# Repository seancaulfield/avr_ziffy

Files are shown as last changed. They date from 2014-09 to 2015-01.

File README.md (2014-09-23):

avr_ziffy
=========

Arduino shield with a plethora of ZIF sockets to allow programming of all the
various Atmel AVR chips.

The hardware directory should contain the Eagle CAD project files needed to
build the board. Since they're Not Exactly Code but still open hardware, I'm
licensing them under Creative Commons Attribution Share Alike license.

I've modified the sample code provided with the Arduino distribution for the
firmware files, both because I needed to ensure all the pins would line up and
also do fix a few problems/lack of clarity in the source code Sicne this was
originally under a 2-clause BSD license, I will stick to that for my fork of
the code.

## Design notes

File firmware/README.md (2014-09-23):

avr_ziffy - Firmware
=========

I've modified the sample code provided with the Arduino distribution for the
firmware files, both because I needed to ensure all the pins would line up and
also do fix a few problems/lack of clarity in the source code Sicne this was
originally under a 2-clause BSD license, I will stick to that for my fork of
the code.

I've been using the Python CLI tool ino to handle building w/o using the
Arduino GUI, which is why the directory layout and wierdo ino.ini file.
However, it should be backwards compatible with the Arduino GUI.

No libraries outside of the basic Arduino ones should be required.

The bulk of credit of course goes to those developers who have gone before me:
* Randall Bohn
* David A. Mellis

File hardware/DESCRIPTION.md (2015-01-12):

"ZIFfy" AVR ISP Shield
======================

Summary
-------

Riff on the version(s) from SparkFun, EvilMadScientist, and my own insane ideas while trying to learn to use EAGLE.

Licensed under the Creative Commons, version 4.0 ported, attribution & share-alike (CC-4.0-BY-SA).

Revision History
----------------

*Revison 1.0* - TODO

*Revison 2.0* - TODO

*Revison 3.0* - TODO

*Revison 4.0* - Relayout, including punting the DIP20 socket that I've yet to use as well as shortening the whole shield for cost reasons. Clock and voltage select support removed since they didn't seem to be necessary, either.

*Revison 5.0* - Instead of using separate ZIF sockets, use a ridiculous 6P4T mechanical switch to select which lines go to which pins. Supports programming any AVR via the ISP connector, and the following via the onboard ZIF socket:

* ATTiny 25/45/85
* ATTiny 24/44/84
* ATTiny 2313/4313
* ATMega 328P

*Revison 6.0* - Instead of using separate ZIF sockets or a ridiculous 6P4T mechanical switch, use 6 74'125 buffer chips to drive the various lines to the correct pins. Mostly pin compatibile with existing firmware, but to properly use the buffers requires 4 more GPIO lines to select the chip type. Supports programming any AVR via the ISP connector, and the following via the onboard ZIF socket:
* ATTiny 25/45/85
* ATTiny 24/44/84
* ATTiny 2313/4313
* ATMega 328P

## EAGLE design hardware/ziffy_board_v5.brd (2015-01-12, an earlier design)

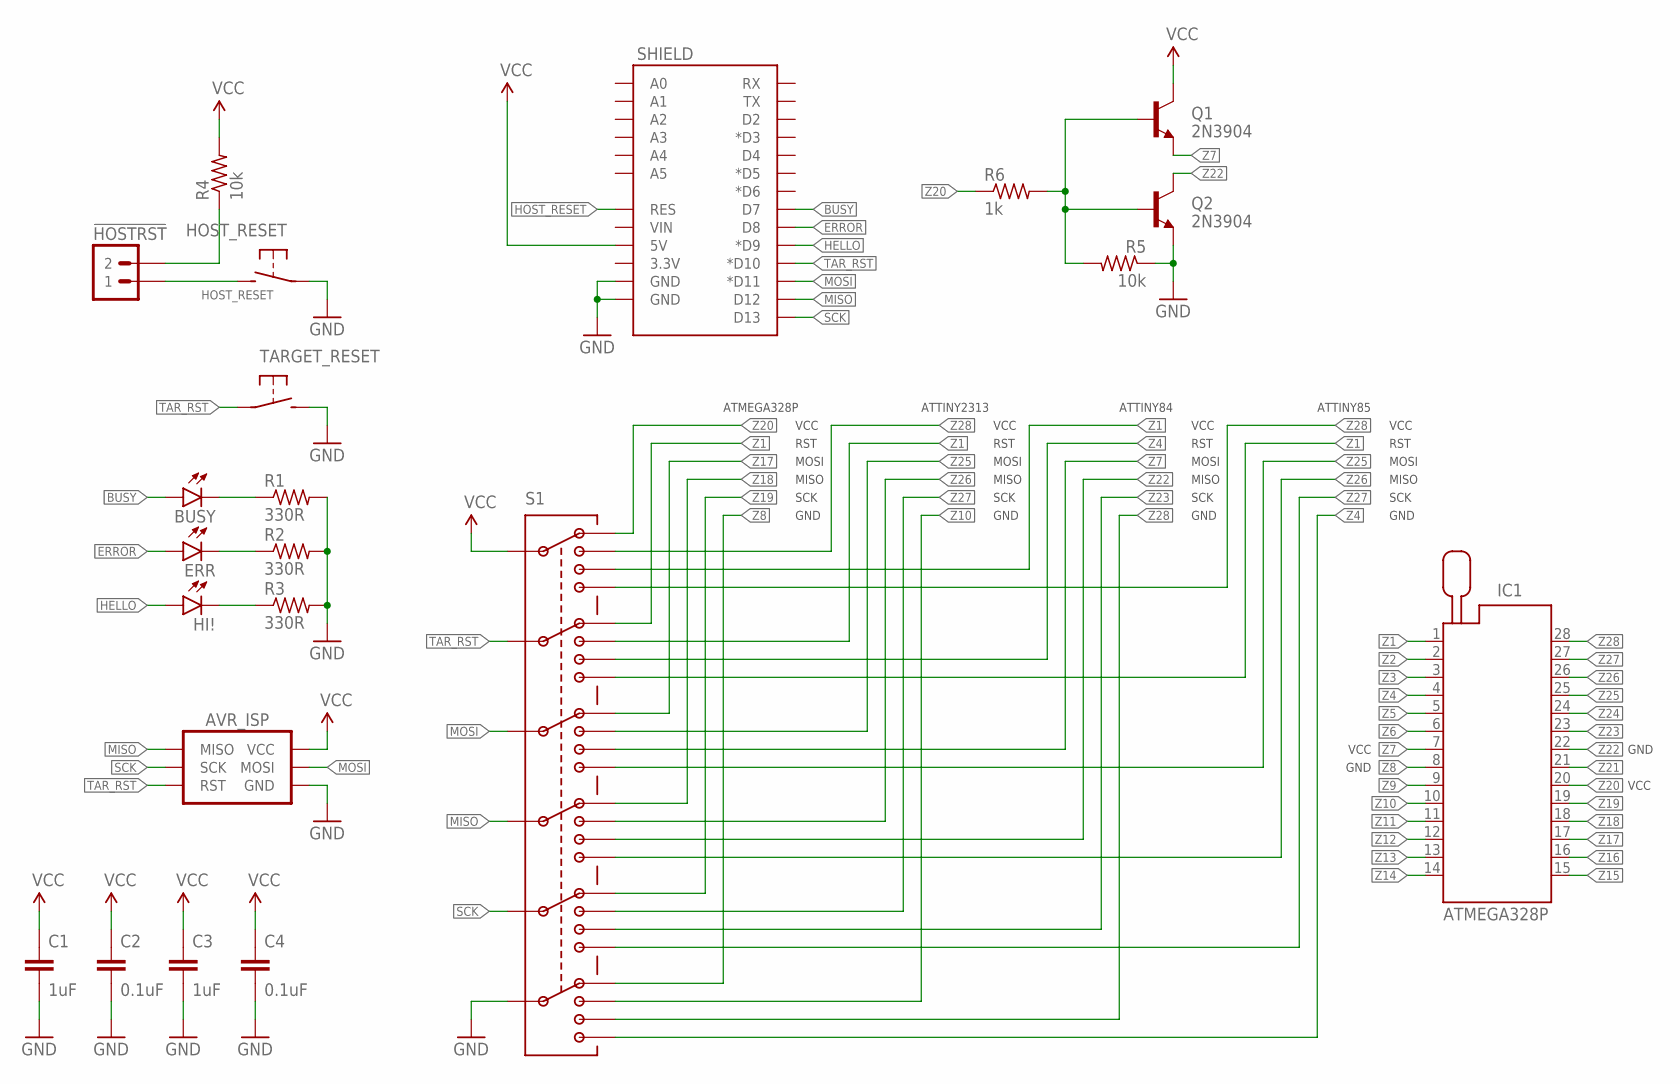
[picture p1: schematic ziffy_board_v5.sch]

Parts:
!HOSTRST: M02PTH; 1X02
AVR_ISP: AVR_SPI_PRG_6PTH-SHROUD; 2X3-SHROUDED
BUSY: YELLOW; LED3MM
C1, C3: 1uF; C025-024X044
C2, C4: 0.1uF; C025-024X044
ERR: RED; LED3MM
HI!: GREEN; LED3MM
HOST_RESET: SPST-NO-TACT6MM-PTH-SMALL-PADS; DTS-6-SMALL-PADS
IC1: ATMEGA328P; ZIF28
Q1, Q2: 2N3904; TO-92-AMMO
R1, R2, R3: 330R; RESISTOR-AXIAL-PTH-6.35MM
R4, R5: 10k; RESISTOR-AXIAL-PTH-6.35MM
R6: 1k; RESISTOR-AXIAL-PTH-6.35MM
S1: SWITCH-6P4TASDFADSFSD; SWITCH-6P4T-2MMPTH
SHIELD: ARDUINO_SHIELD_SMALLER; ARDUINO_SHIELD_NOOUTLINE_INSIDE_SMALLER
TARGET_RESET: SPST-NO-TACT6MM-PTH-SMALL-PADS; DTS-6-SMALL-PADS

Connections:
BUSY: BUSY.A, SHIELD.D7
ERROR: ERR.A, SHIELD.D8
GND: AVR_ISP.6 (GND), C1.2, C2.2, C3.2, C4.2, HOST_RESET.1, HOST_RESET.2 (1), Q2.1 (E), R1.P$2 (2), R2.P$2 (2), R3.P$2 (2), R5.P$1 (1), S1.P28 (28), SHIELD.GND@0 (GND), SHIELD.GND@1 (GND), TARGET_RESET.3 (2), TARGET_RESET.4 (2)
HELLO: HI!.A, SHIELD.D9 (*D9)
HOST_RESET: !HOSTRST.1, HOST_RESET.3 (2), HOST_RESET.4 (2), SHIELD.RES
MISO: AVR_ISP.1 (MISO), S1.P18 (18), SHIELD.D12
MOSI: AVR_ISP.4 (MOSI), S1.P13 (13), SHIELD.D11 (*D11)
unnamed: BUSY.K (C), R1.P$1 (1)
unnamed: ERR.K (C), R2.P$1 (1)
unnamed: HI!.K (C), R3.P$1 (1)
unnamed: !HOSTRST.2, R4.P$1 (1)
unnamed: Q1.2 (B), Q2.2 (B), R5.P$2 (2), R6.P$2 (2)
SCK: AVR_ISP.3 (SCK), S1.P23 (23), SHIELD.D13
TAR_RST: AVR_ISP.5 (RST), S1.P8 (8), SHIELD.D10 (*D10), TARGET_RESET.1, TARGET_RESET.2 (1)
VCC: AVR_ISP.2 (VCC), C1.1, C2.1, C3.1, C4.1, Q1.3 (C), R4.P$2 (2), S1.P3 (3), SHIELD.5V
Z1: IC1.1, S1.P4 (4), S1.P6 (6), S1.P7 (7), S1.P10 (10)
Z2: IC1.2
Z3: IC1.3
Z4: IC1.4, S1.P9 (9), S1.P30 (30)
Z5: IC1.5
Z6: IC1.6
Z7: IC1.7, Q1.1 (E), S1.P14 (14)
Z8: IC1.8, S1.P26 (26)
Z9: IC1.9
Z10: IC1.10, S1.P27 (27)
Z11: IC1.11
Z12: IC1.12
Z13: IC1.13
Z14: IC1.14
Z15: IC1.15
Z16: IC1.16
Z17: IC1.17, S1.P11 (11)
Z18: IC1.18, S1.P16 (16)
Z19: IC1.19, S1.P21 (21)
Z20: IC1.20, R6.P$1 (1), S1.P1 (1)
Z21: IC1.21
Z22: IC1.22, Q2.3 (C), S1.P19 (19)
Z23: IC1.23, S1.P24 (24)
Z24: IC1.24
Z25: IC1.25, S1.P12 (12), S1.P15 (15)
Z26: IC1.26, S1.P17 (17), S1.P20 (20)
Z27: IC1.27, S1.P22 (22), S1.P25 (25)
Z28: IC1.28, S1.P2 (2), S1.P5 (5), S1.P29 (29)

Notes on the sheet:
ATMEGA328P
ATTINY2313
ATTINY84
ATTINY85
VCC
RST
MOSI
MISO
SCK
GND

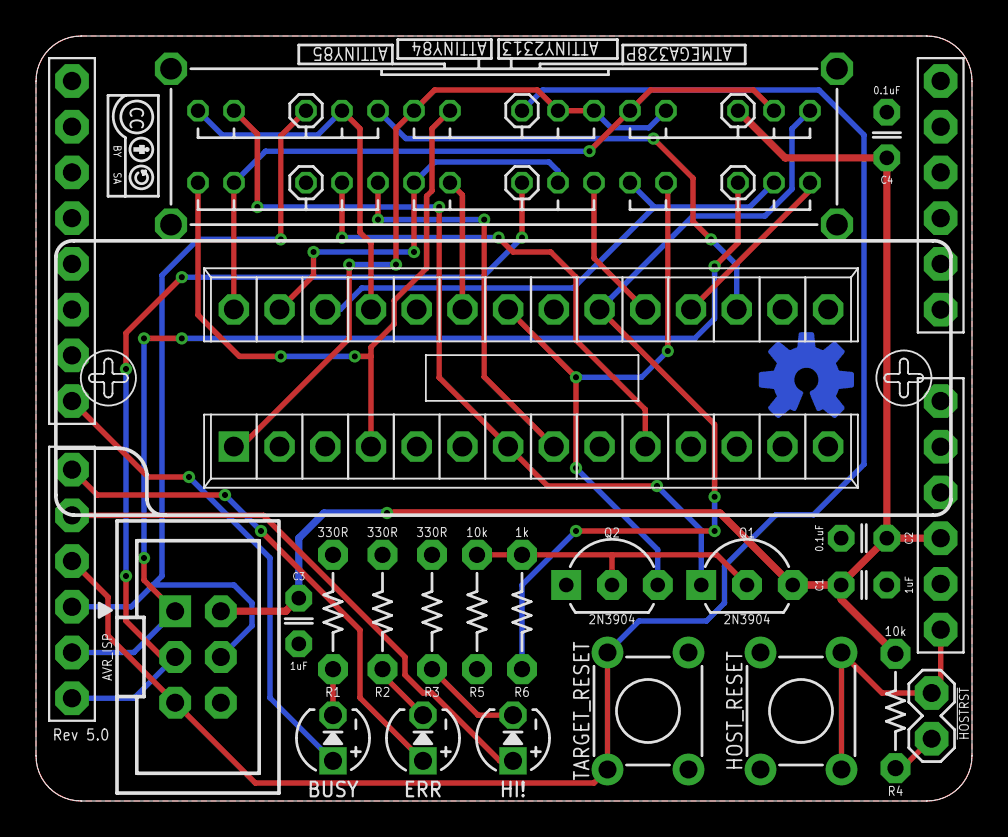
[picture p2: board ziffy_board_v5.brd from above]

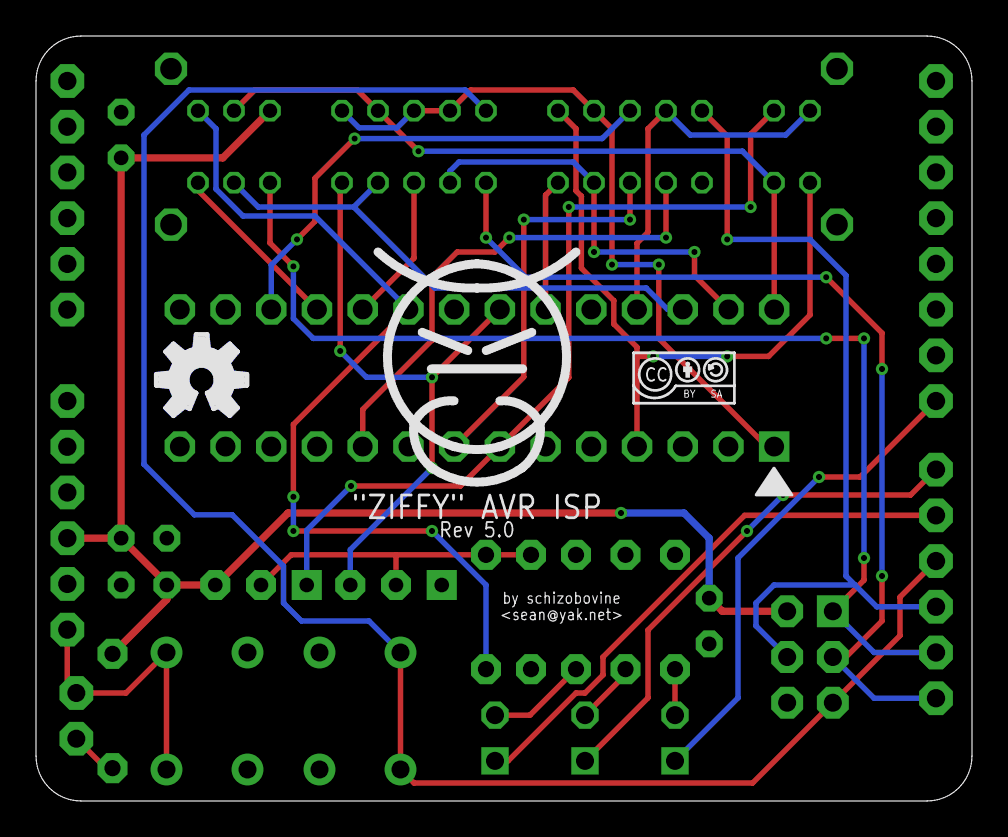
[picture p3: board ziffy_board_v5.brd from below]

Board: 2 copper layers, 52.0 x 42.5 mm, 26 parts (2 on the bottom side), 30 nets.

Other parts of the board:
U$1, U$5: CC-BY-SA-4.0-NO-URL
U$2: COW
U$3: OSHWLOGO_BOT_0.2

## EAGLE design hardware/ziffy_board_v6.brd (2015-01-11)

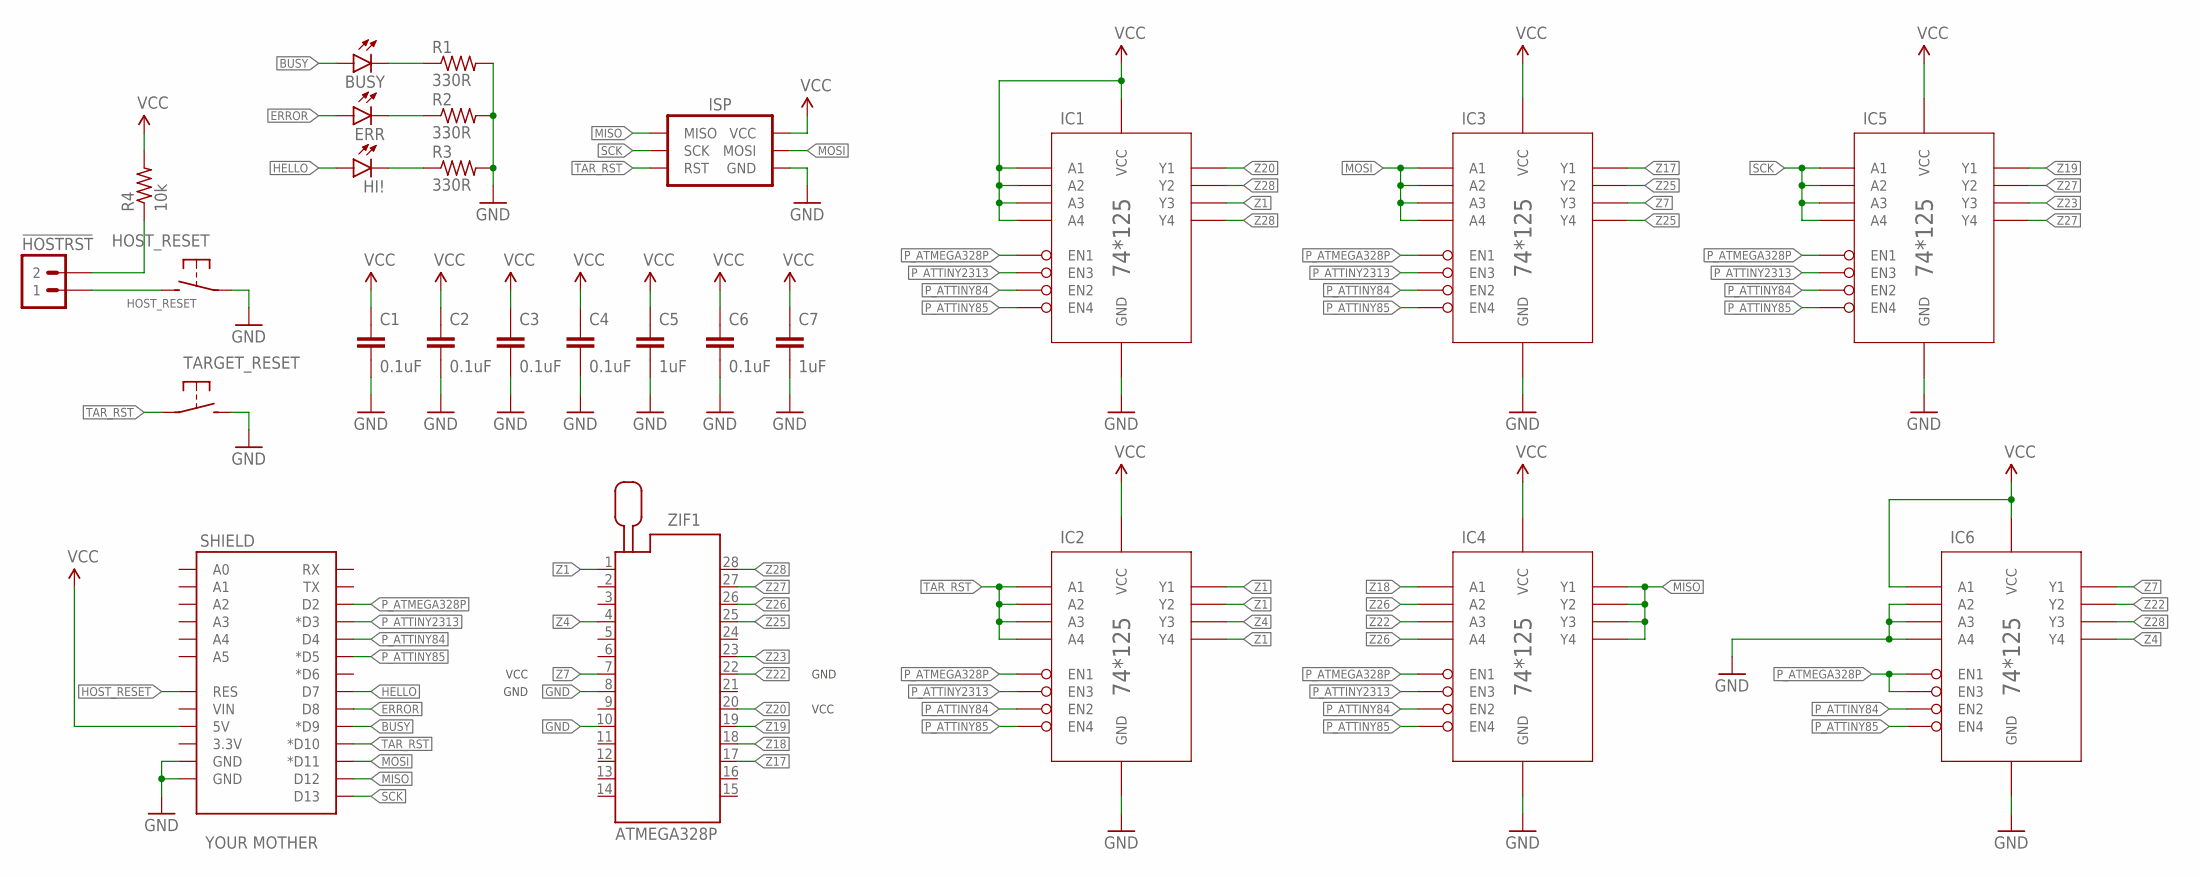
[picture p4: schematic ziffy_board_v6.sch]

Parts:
!HOSTRST: M02PTH; 1X02
BUSY: YELLOW; LED3MM
C1, C2, C3, C4, C6: 0.1uF; C025-024X044
C5, C7: 1uF; C025-024X044
ERR: RED; LED3MM
HI!: GREEN; LED3MM
HOST_RESET: SPST-NO-TACT6MM-PTH-SMALL-PADS; DTS-6-SMALL-PADS
IC1, IC2, IC3, IC4, IC5, IC6: 74HC125; SO14
ISP: AVR_SPI_PRG_6PTH-SHROUD; 2X3-SHROUDED
R1, R2, R3: 330R; RESISTOR-AXIAL-PTH-5.08MM
R4: 10k; RESISTOR-AXIAL-PTH-5.08MM
SHIELD: YOUR MOTHER; ARDUINO_SHIELD_NOOUTLINE_INSIDE_SMALLER
TARGET_RESET: SPST-NO-TACT6MM-PTH-SMALL-PADS; DTS-6-SMALL-PADS
ZIF1: ATMEGA328P; ZIF28

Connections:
BUSY: BUSY.A, SHIELD.D9 (*D9)
ERROR: ERR.A, SHIELD.D8
GND: C1.2, C2.2, C3.2, C4.2, C5.2, C6.2, C7.2, HOST_RESET.1, HOST_RESET.2 (1), IC1.7 (GND), IC2.7 (GND), IC3.7 (GND), IC4.7 (GND), IC5.7 (GND), IC6.5 (A2), IC6.7 (GND), IC6.9 (A3), IC6.12 (A4), ISP.6 (GND), R1.P$2 (2), R2.P$2 (2), R3.P$2 (2), SHIELD.GND@0 (GND), SHIELD.GND@1 (GND), TARGET_RESET.3 (2), TARGET_RESET.4 (2), ZIF1.8, ZIF1.10
HELLO: HI!.A, SHIELD.D7
HOST_RESET: !HOSTRST.1, HOST_RESET.3 (2), HOST_RESET.4 (2), SHIELD.RES
MISO: IC4.3 (Y1), IC4.6 (Y2), IC4.8 (Y3), IC4.11 (Y4), ISP.1 (MISO), SHIELD.D12
MOSI: IC3.2 (A1), IC3.5 (A2), IC3.9 (A3), IC3.12 (A4), ISP.4 (MOSI), SHIELD.D11 (*D11)
unnamed: BUSY.K (C), R1.P$1 (1)
unnamed: ERR.K (C), R2.P$1 (1)
unnamed: HI!.K (C), R3.P$1 (1)
unnamed: !HOSTRST.2, R4.P$1 (1)
P_ATMEGA328P: IC1.1 (EN1), IC2.1 (EN1), IC3.1 (EN1), IC4.1 (EN1), IC5.1 (EN1), IC6.1 (EN1), IC6.10 (EN3), SHIELD.D2
P_ATTINY84: IC1.4 (EN2), IC2.4 (EN2), IC3.4 (EN2), IC4.4 (EN2), IC5.4 (EN2), IC6.4 (EN2), SHIELD.D4
P_ATTINY85: IC1.13 (EN4), IC2.13 (EN4), IC3.13 (EN4), IC4.13 (EN4), IC5.13 (EN4), IC6.13 (EN4), SHIELD.D5 (*D5)
P_ATTINY2313: IC1.10 (EN3), IC2.10 (EN3), IC3.10 (EN3), IC4.10 (EN3), IC5.10 (EN3), SHIELD.D3 (*D3)
SCK: IC5.2 (A1), IC5.5 (A2), IC5.9 (A3), IC5.12 (A4), ISP.3 (SCK), SHIELD.D13
TAR_RST: IC2.2 (A1), IC2.5 (A2), IC2.9 (A3), IC2.12 (A4), ISP.5 (RST), SHIELD.D10 (*D10), TARGET_RESET.1, TARGET_RESET.2 (1)
VCC: C1.1, C2.1, C3.1, C4.1, C5.1, C6.1, C7.1, IC1.2 (A1), IC1.5 (A2), IC1.9 (A3), IC1.12 (A4), IC1.14 (VCC), IC2.14 (VCC), IC3.14 (VCC), IC4.14 (VCC), IC5.14 (VCC), IC6.2 (A1), IC6.14 (VCC), ISP.2 (VCC), R4.P$2 (2), SHIELD.5V
Z1: IC1.8 (Y3), IC2.3 (Y1), IC2.6 (Y2), IC2.11 (Y4), ZIF1.1
Z4: IC2.8 (Y3), IC6.11 (Y4), ZIF1.4
Z7: IC3.8 (Y3), IC6.3 (Y1), ZIF1.7
Z17: IC3.3 (Y1), ZIF1.17
Z18: IC4.2 (A1), ZIF1.18
Z19: IC5.3 (Y1), ZIF1.19
Z20: IC1.3 (Y1), ZIF1.20
Z22: IC4.9 (A3), IC6.6 (Y2), ZIF1.22
Z23: IC5.8 (Y3), ZIF1.23
Z25: IC3.6 (Y2), IC3.11 (Y4), ZIF1.25
Z26: IC4.5 (A2), IC4.12 (A4), ZIF1.26
Z27: IC5.6 (Y2), IC5.11 (Y4), ZIF1.27
Z28: IC1.6 (Y2), IC1.11 (Y4), IC6.8 (Y3), ZIF1.28

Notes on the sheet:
VCC
GND

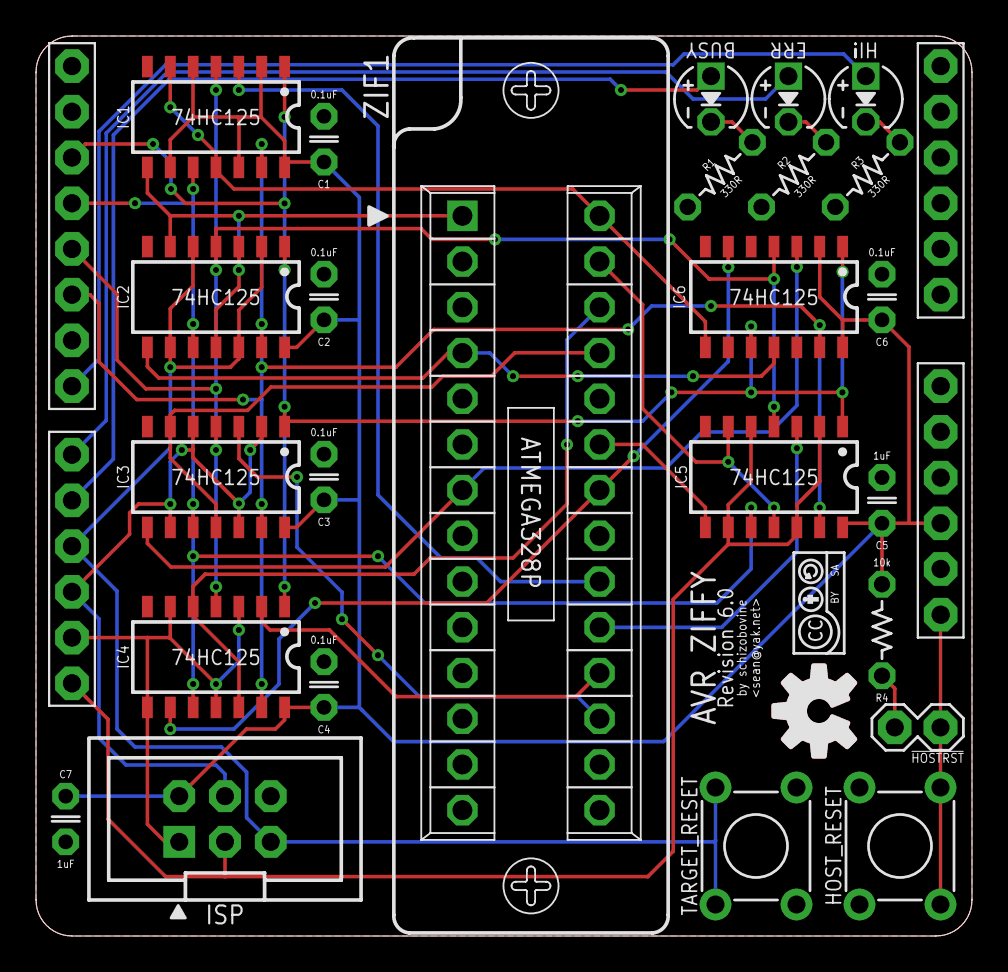
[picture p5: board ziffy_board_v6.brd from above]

Board: 2 copper layers, 52.0 x 50.0 mm, 28 parts (0 on the bottom side), 31 nets.

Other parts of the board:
U$1: CC-BY-SA-4.0-NO-URL
U$2: OSHWLOGO_TOP_0.2_A

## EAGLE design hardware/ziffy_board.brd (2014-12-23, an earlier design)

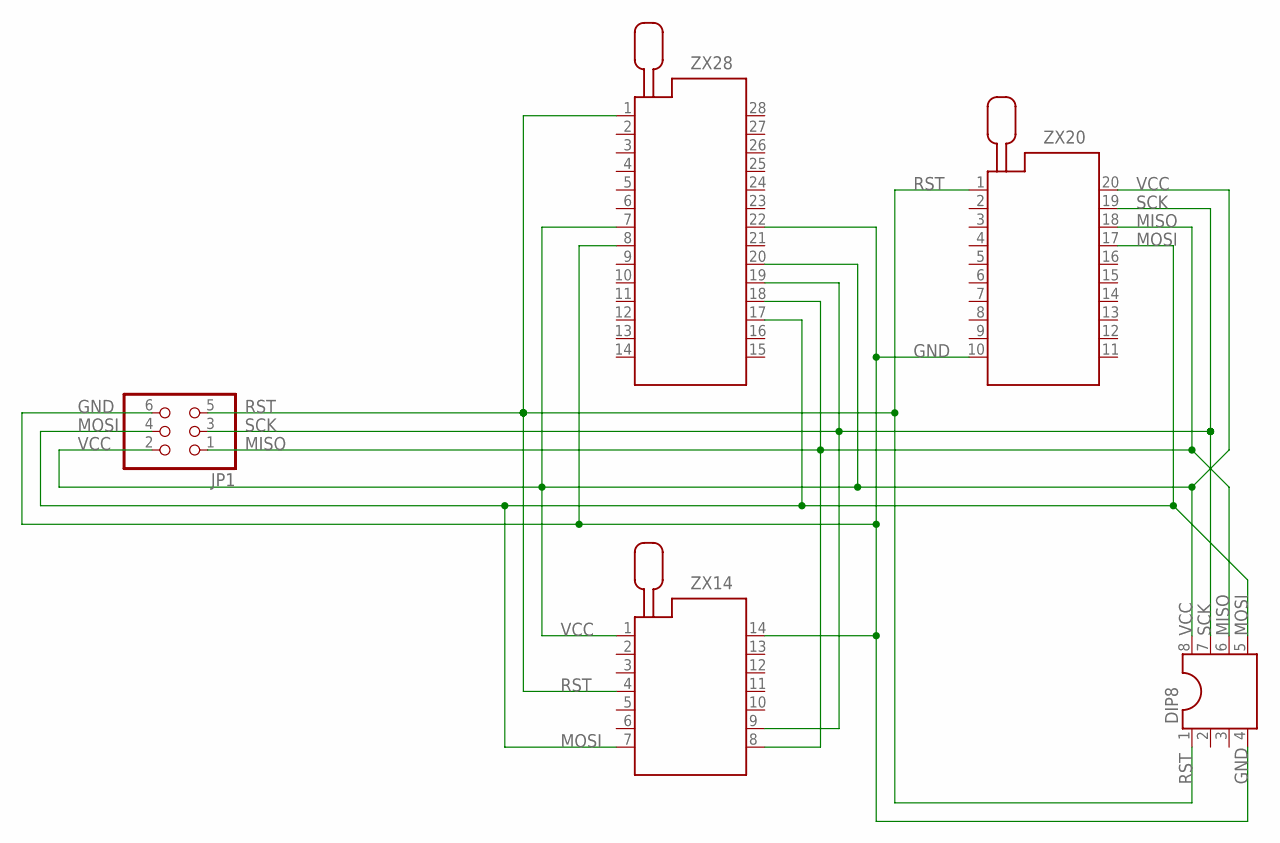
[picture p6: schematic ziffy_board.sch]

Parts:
DIP8: DIL8S; SOCKET-08
JP1: PINHD-2X3; 2X03
ZX14: 214-3339-00-0602J
ZX20: 220-3342-00-0602J
ZX28: 228-4817-00-0602J

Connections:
GND: DIP8.4, JP1.6, ZX14.14, ZX20.10, ZX28.8, ZX28.22
MISO: DIP8.6, JP1.1, ZX14.8, ZX20.18, ZX28.18
MOSI: DIP8.5, JP1.4, ZX14.7, ZX20.17, ZX28.17
RST: DIP8.1, JP1.5, ZX14.4, ZX20.1, ZX28.1
SCK: DIP8.7, JP1.3, ZX14.9, ZX20.19, ZX28.19
VCC: DIP8.8, JP1.2, ZX14.1, ZX20.20, ZX28.7, ZX28.20

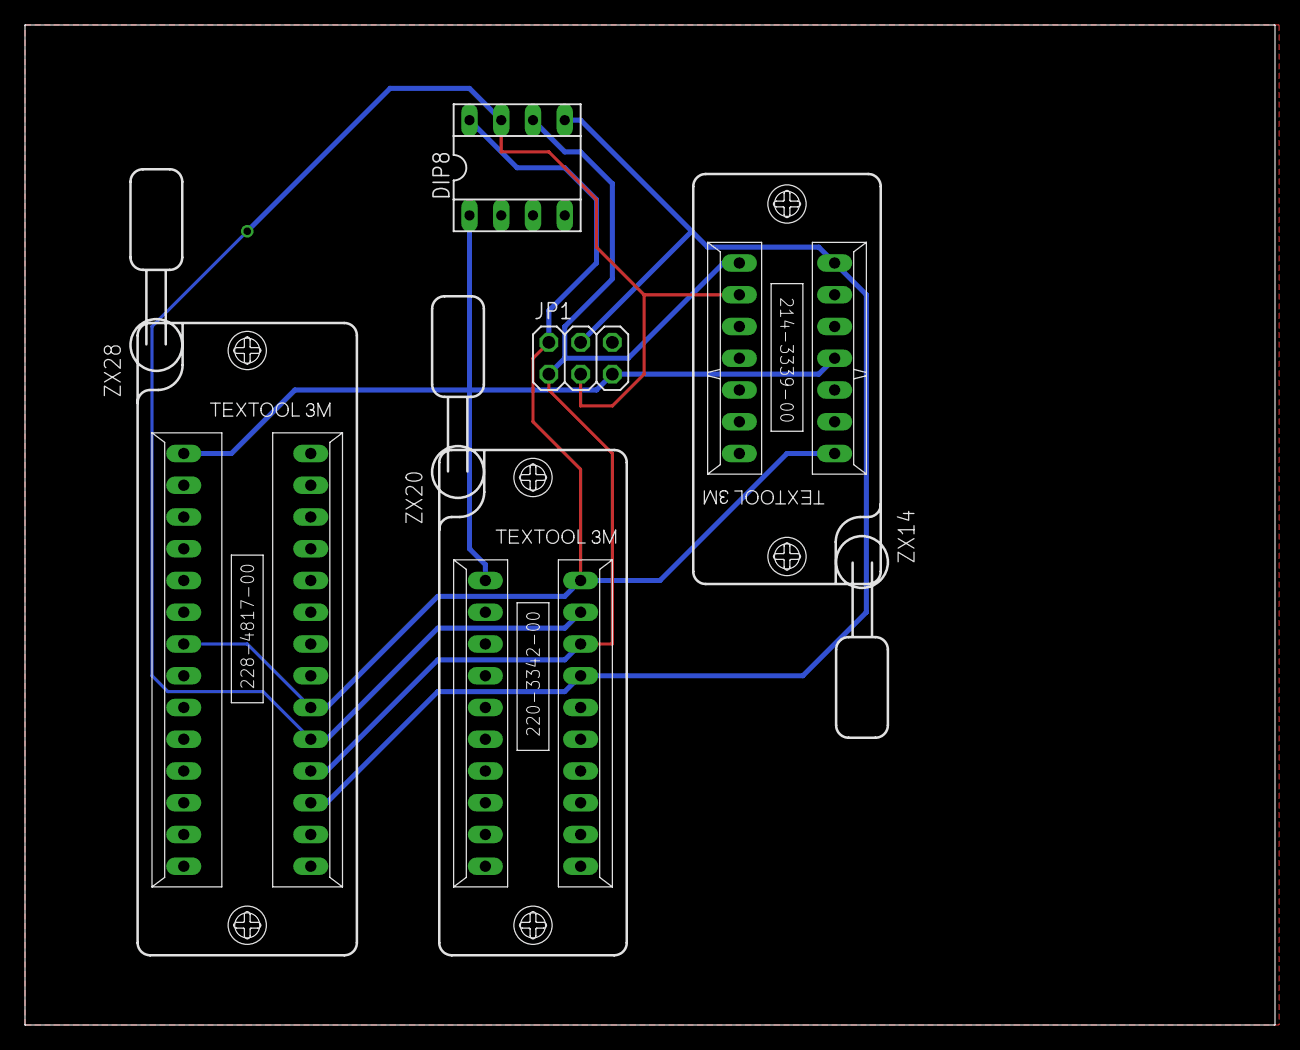
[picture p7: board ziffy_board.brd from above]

Board: 2 copper layers, 100.0 x 80.0 mm, 5 parts (0 on the bottom side), 6 nets.

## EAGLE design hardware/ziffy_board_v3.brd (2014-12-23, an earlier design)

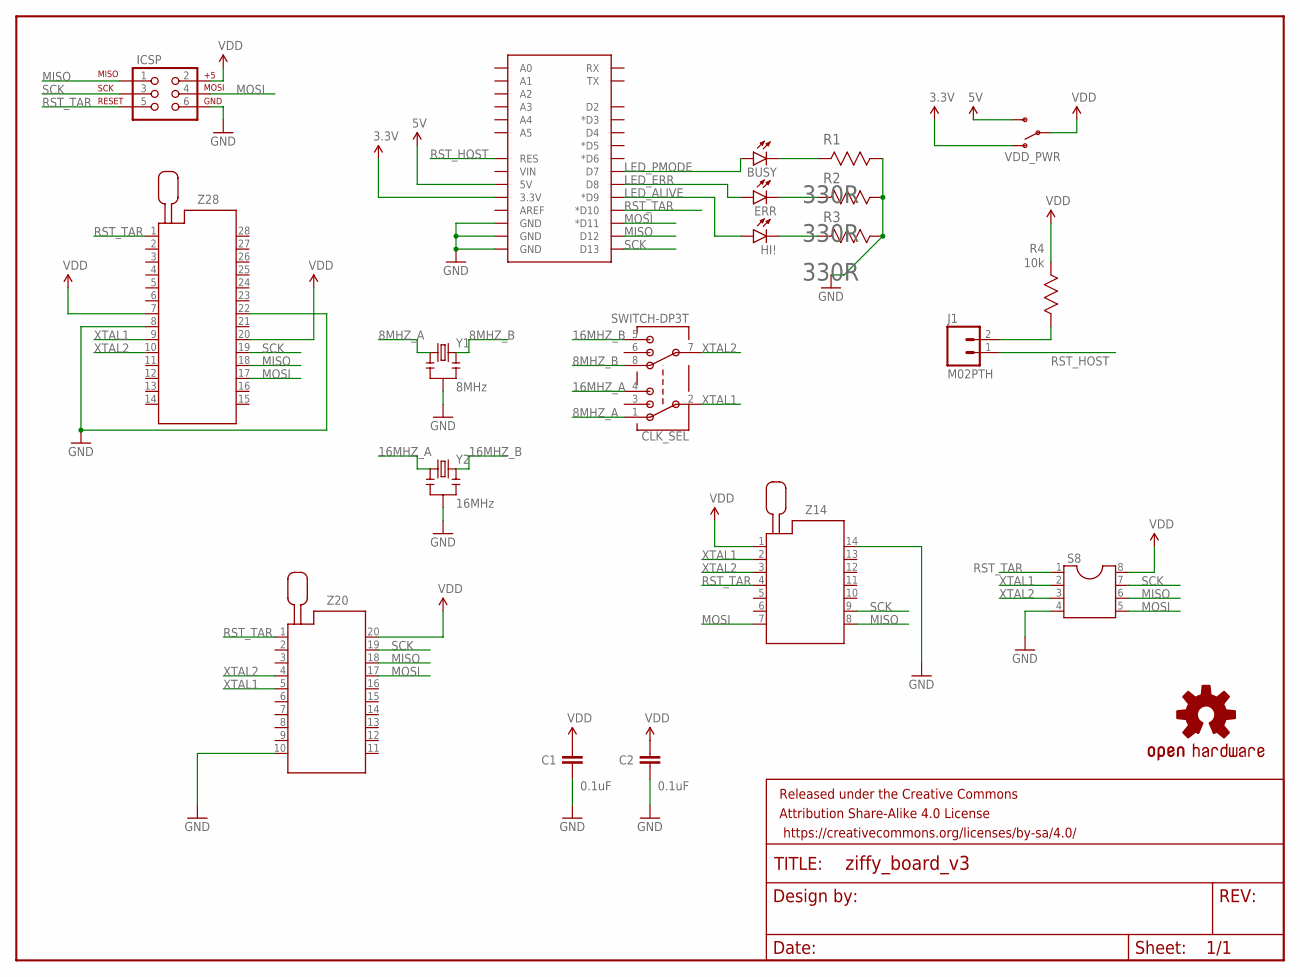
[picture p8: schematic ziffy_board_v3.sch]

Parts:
BUSY: YELLOW; LED3MM
C1, C2: 0.1uF; CAP-PTH-SMALL2
CLK_SEL: SWITCH-DP3T
ERR: RED; LED3MM
FRAME1: FRAME-LETTER; CREATIVE_COMMONS
HI!: GREEN; LED3MM
ICSP: AVR_SPI_PRG_6PTH; 2X3
J1: M02PTH; 1X02
LOGO2: OSHW-LOGOS; OSHW-LOGO-S
R1, R2, R3: 330R; AXIAL-0.2
R4: 10k; AXIAL-0.2
S8: DIPSHIT; DIL08
U$1: ARDUINO_SHIELDOUTLINE_NOHOLES; ARDUINO_SHIELD_OUTLINE_NOHOLES
VDD_PWR: SPDT; SWITCH-SPDT
Y1: 8MHz; RESONATOR-PTH
Y2: 16MHz; RESONATOR-PTH
Z14: ZIF14
Z20: ZIF20
Z28: ZIF28

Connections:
3.3V: U$1.3.3V, VDD_PWR.1 (O)
5V: U$1.5V, VDD_PWR.3 (S)
8MHZ_A: CLK_SEL.1, Y1.1
8MHZ_B: CLK_SEL.8, Y1.3
16MHZ_A: CLK_SEL.4, Y2.1
16MHZ_B: CLK_SEL.5, Y2.3
GND: C1.2, C2.2, ICSP.6, R1.P$1 (2), R2.P$1 (2), R3.P$1 (2), S8.4, U$1.GND@0 (GND), U$1.GND@1 (GND), U$1.GND@2 (GND), Y1.2, Y2.2, Z14.14, Z20.10, Z28.8, Z28.22
LED_ALIVE: HI!.A, U$1.D9 (*D9)
LED_ERR: ERR.A, U$1.D8
LED_PMODE: BUSY.A, U$1.D7
MISO: ICSP.1, S8.6, U$1.D12, Z14.8, Z20.18, Z28.18
MOSI: ICSP.4, S8.5, U$1.D11 (*D11), Z14.7, Z20.17, Z28.17
unnamed: BUSY.K (C), R1.P$2 (1)
unnamed: ERR.K (C), R2.P$2 (1)
unnamed: HI!.K (C), R3.P$2 (1)
unnamed: J1.2, R4.P$1 (2)
RST_HOST: J1.1, U$1.RES
RST_TAR: ICSP.5, S8.1, U$1.D10 (*D10), Z14.4, Z20.1, Z28.1
SCK: ICSP.3, S8.7, U$1.D13, Z14.9, Z20.19, Z28.19
VDD: C1.1, C2.1, ICSP.2, R4.P$2 (1), S8.8, VDD_PWR.2, Z14.1, Z20.20, Z28.7, Z28.20
XTAL1: CLK_SEL.2, S8.2, Z14.2, Z20.5, Z28.9
XTAL2: CLK_SEL.7, S8.3, Z14.3, Z20.4, Z28.10

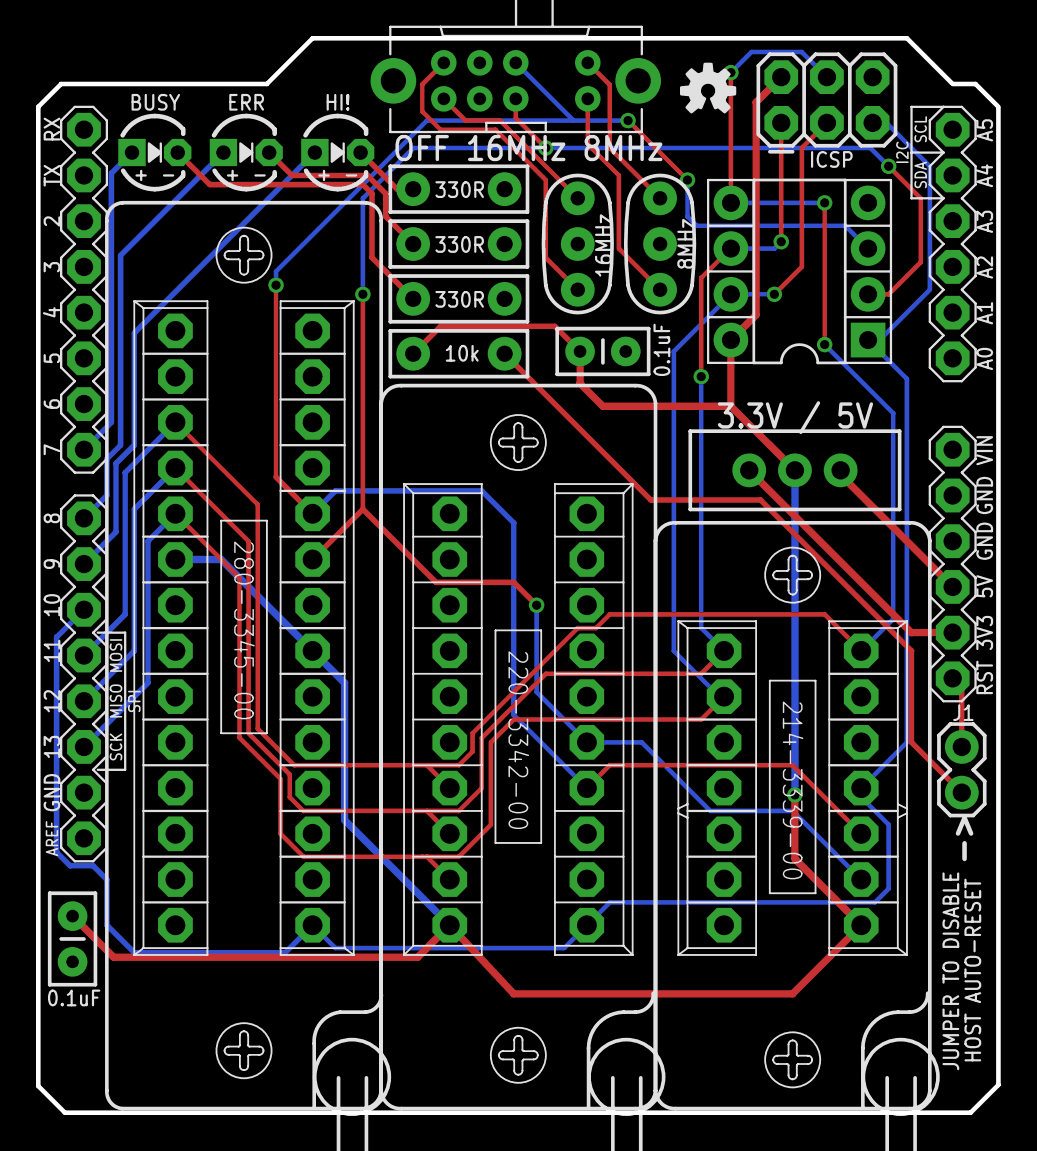
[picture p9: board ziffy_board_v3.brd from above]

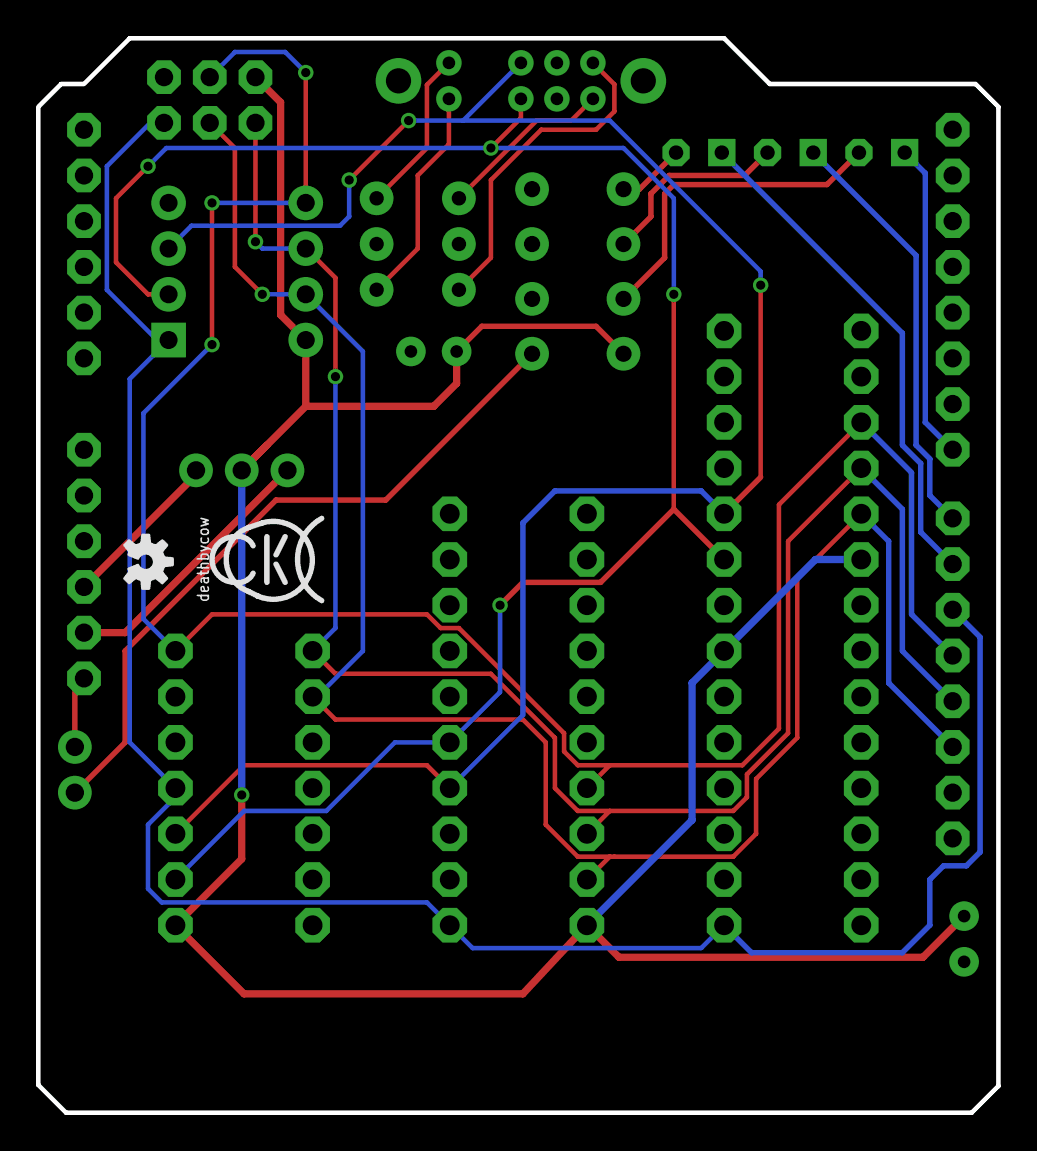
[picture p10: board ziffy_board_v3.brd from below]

Board: 2 copper layers, 53.3 x 59.7 mm, 24 parts (2 on the bottom side), 22 nets.

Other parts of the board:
LOGO1: OSHW-LOGOS; OSHW-LOGO-S
U$3: COW_SMALL

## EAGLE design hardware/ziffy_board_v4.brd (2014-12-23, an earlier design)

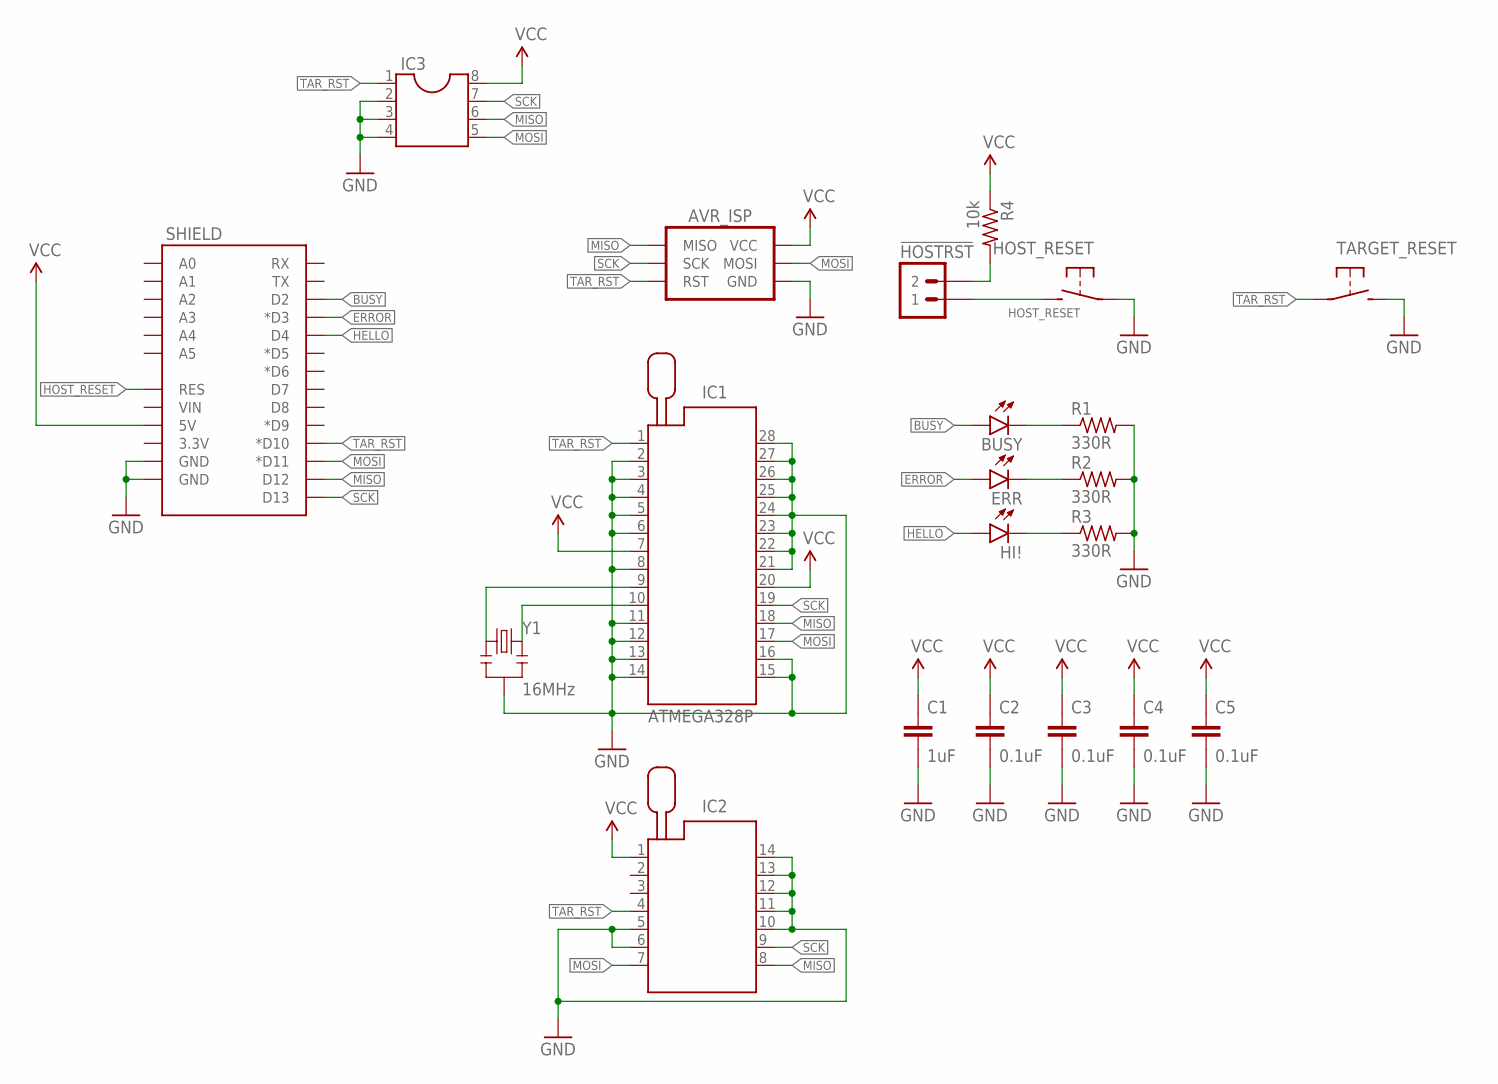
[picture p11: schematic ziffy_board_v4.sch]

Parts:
!HOSTRST: M02PTH; 1X02
AVR_ISP: AVR_SPI_PRG_6PTH-SHROUD; 2X3-SHROUDED
BUSY: YELLOW; LED3MM
C1: 1uF; C025-024X044
C2, C3, C4, C5: 0.1uF; C025-024X044
ERR: RED; LED3MM
HI!: GREEN; LED3MM
HOST_RESET: SPST-NO-TACT3MM-PTH-SMALL-PADS; DTS-3-SMALL-PADS
IC1: ATMEGA328P; ZIF28
IC2: ATTINY84; ZIF14
IC3: DIL8; DIL08
R1, R2, R3: 330R; RESISTOR-AXIAL-PTH-6.35MM
R4: 10k; RESISTOR-AXIAL-PTH-5.08MM
SHIELD: ARDUINO_SHIELD_SMALLER; ARDUINO_SHIELD_NOOUTLINE_INSIDE_SMALLER
TARGET_RESET: SPST-NO-TACT3MM-PTH-SMALL-PADS; DTS-3-SMALL-PADS
Y1: 16MHz; RESONATOR-PTH

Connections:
BUSY: BUSY.A, SHIELD.D2
ERROR: ERR.A, SHIELD.D3 (*D3)
GND: AVR_ISP.6 (GND), C1.2, C2.2, C3.2, C4.2, C5.2, HOST_RESET.1, IC1.2, IC1.3, IC1.4, IC1.5, IC1.6, IC1.8, IC1.11, IC1.12, IC1.13, IC1.14, IC1.15, IC1.16, IC1.21, IC1.22, IC1.23, IC1.24, IC1.25, IC1.26, IC1.27, IC1.28, IC2.5, IC2.6, IC2.10, IC2.11, IC2.12, IC2.13, IC2.14, IC3.2, IC3.3, IC3.4, R1.P$2 (2), R2.P$2 (2), R3.P$2 (2), SHIELD.GND@0 (GND), SHIELD.GND@1 (GND), TARGET_RESET.2, Y1.2
HELLO: HI!.A, SHIELD.D4
HOST_RESET: !HOSTRST.1, HOST_RESET.2, SHIELD.RES
MISO: AVR_ISP.1 (MISO), IC1.18, IC2.8, IC3.6, SHIELD.D12
MOSI: AVR_ISP.4 (MOSI), IC1.17, IC2.7, IC3.5, SHIELD.D11 (*D11)
unnamed: BUSY.K (C), R1.P$1 (1)
unnamed: ERR.K (C), R2.P$1 (1)
unnamed: HI!.K (C), R3.P$1 (1)
unnamed: !HOSTRST.2, R4.P$2 (2)
unnamed: IC1.9, Y1.1
unnamed: IC1.10, Y1.3
SCK: AVR_ISP.3 (SCK), IC1.19, IC2.9, IC3.7, SHIELD.D13
TAR_RST: AVR_ISP.5 (RST), IC1.1, IC2.4, IC3.1, SHIELD.D10 (*D10), TARGET_RESET.1
VCC: AVR_ISP.2 (VCC), C1.1, C2.1, C3.1, C4.1, C5.1, IC1.7, IC1.20, IC2.1, IC3.8, R4.P$1 (1), SHIELD.5V

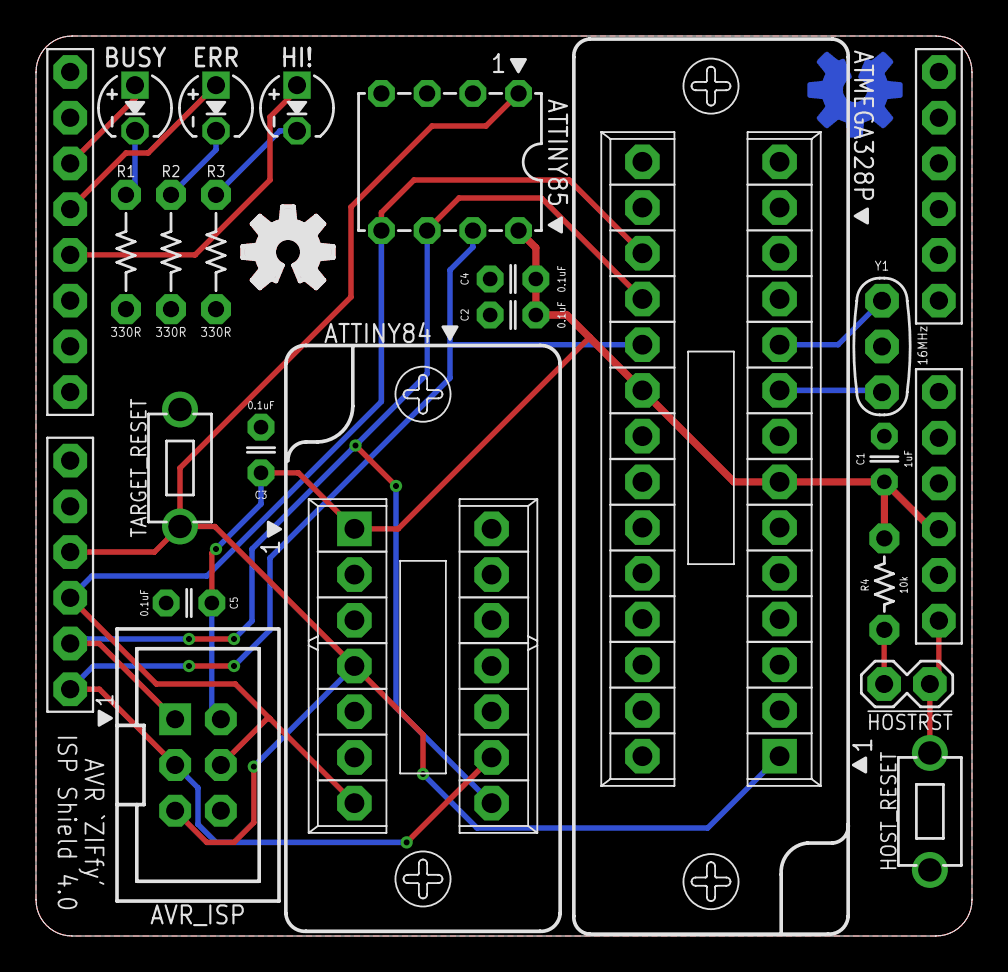
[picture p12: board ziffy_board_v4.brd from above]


Board: 2 copper layers, 52.0 x 50.0 mm, 25 parts (3 on the bottom side), 16 nets.

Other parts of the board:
U$2: CC-BY-SA-4.0-NO-URL
U$3: COW
U$5, U$6: OSHWLOGO_TOP_0.2

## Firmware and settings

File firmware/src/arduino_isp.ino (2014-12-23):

// ArduinoISP version 04m3
// Copyright (c) 2008-2011 Randall Bohn
// If you require a license, see 
//     http://www.opensource.org/licenses/bsd-license.php
//
// This sketch turns the Arduino into a AVRISP
// using the following arduino pins:
//
// pin name:    not-mega:         mega(1280 and 2560)
// slave reset: 10:               53 
// MOSI:        11:               51 
// MISO:        12:               50 
// SCK:         13:               52 
//
// Put an LED (with resistor) on the following pins:
// 9: Heartbeat   - shows the programmer is running
// 8: Error       - Lights up if something goes wrong (use red if that makes sense)
// 7: Programming - In communication with the slave
//
// 23 July 2011 Randall Bohn
// -Address Arduino issue 509 :: Portability of ArduinoISP
// http://code.google.com/p/arduino/issues/detail?id=509
//
// October 2010 by Randall Bohn
// - Write to EEPROM > 256 bytes
// - Better use of LEDs:
// -- Flash LED_PMODE on each flash commit
// -- Flash LED_PMODE while writing EEPROM (both give visual feedback of writing progress)
// - Light LED_ERR whenever we hit a STK_NOSYNC. Turn it off when back in sync.
// - Use pins_arduino.h (should also work on Arduino Mega)
//
// October 2009 by David A. Mellis
// - Added support for the read signature command
// 
// February 2009 by Randall Bohn
// - Added support for writing to EEPROM (what took so long?)
// Windows users should consider WinAVR's avrdude instead of the
// avrdude included with Arduino software.
//
// January 2008 by Randall Bohn
// - Thanks to Amplificar for helping me with the STK500 protocol
// - The AVRISP/STK500 (mk I) protocol is used in the arduino bootloader
// - The SPI functions herein were developed for the AVR910_ARD programmer 
// - More information at http://code.google.com/p/mega-isp
#include <Arduino.h>
#include "pins_arduino.h"

#define __STDC_LIMIT_MACROS
#include <stdint.h>
#include "arduino_isp.h"

void setup() {

  // Configure serial link to host computer
  Serial.begin(SERIAL_BAUD);

  // Configure & flash LED's on startup
  pinMode(LED_PMODE, OUTPUT);
  pulse(LED_PMODE, 2);
  pinMode(LED_ERR, OUTPUT);
  pulse(LED_ERR, 2);
  pinMode(LED_HB, OUTPUT);
  pulse(LED_HB, 2);

}

// Global error count, which when > 0 causes the error LED to flip on
uint8_t error = 0;

// Whether we're in pmode (I'm assuming Programming mode) or not, which seems
// to be controlled by the host doing the programming
bool pmode = 0;

// Address for reading and writing, set by 'U' command
size_t curr_addr = 0;

// global block storage
uint8_t buff[256];

// Parsed command packet from host
parameter param;

// Used to track the heartbeat pulsing
uint8_t hb_val = HB_STARTING;
int8_t hb_delta = HB_DELTA;

// Heartbeat on pin 9, which slowly pulses the pin
void heartbeat() {

  // Flip sign when we hit the limit values to change direction
  if (hb_val > HB_MAX || hb_val < HB_MIN) {
    hb_delta = -hb_delta;
  }

  // Bump current brightness value & set output pin to match.
  hb_val += hb_delta;
  analogWrite(LED_HB, hb_val);

  delay(HB_RATE);
}

// Increment error counter, checking for & preventing overflow. Returns the
// current error count.
uint8_t error_inc() {
  if (error != 0xFF) {
    error++;
  }
  return error;
}

// Reset error counter to 0
uint8_t error_rst() {
  error = 0;
  return error;
}

void loop(void) {

  // Write out programming mode status
  digitalWrite(LED_PMODE, (pmode ? HIGH : LOW));

  // Write out error status
  digitalWrite(LED_ERR, (error ? HIGH : LOW));

  // light the heartbeat LED
  heartbeat();
  if (Serial.available()) {
    avrisp();
  }
}

// Read a single byte from the serial link
uint8_t getch() {
  uint8_t c;

  // Wait for available data
  while (!Serial.available())
    ;

  // Read and return character. Using temp variable in case we need to detect
  // something like EOF (representing the host resetting our terminal or
  // whatever).
  c = Serial.read();
  return c;
}

// Read n bytes from the serial link and store them in the global buffer
// (starting at 0, thus obliterating anything already thre.
void fill(int n) {
  for (int x = 0; x < n; x++) {
    buff[x] = getch();
  }
}

// Set the pin to HIGH, <times>, for PTIME ms, then back to LOW
void pulse(int pin, int times) {
  do {
    digitalWrite(pin, HIGH);
    delay(PTIME);
    digitalWrite(pin, LOW);
    delay(PTIME);
  } 
  while (times--);
}

// Set the programming LED to the given state
void prog_lamp(int state) {
  if (PROG_FLICKER) {
    digitalWrite(LED_PMODE, state);
  }
}

void spi_init() {
  uint8_t x;
  SPCR = 0x53;
  x=SPSR;
  x=SPDR;
}

void spi_wait() {
  do {
  } 
  while (!(SPSR & (1 << SPIF)));
}

uint8_t spi_send(uint8_t b) {
  uint8_t reply;
  SPDR=b;
  spi_wait();
  reply = SPDR;
  return reply;
}

uint8_t spi_transaction(uint8_t a, uint8_t b, uint8_t c, uint8_t d) {
  uint8_t n;
  spi_send(a); 
  n=spi_send(b);
  n=spi_send(c);
  return spi_send(d);
}

void empty_reply() {
  if (CRC_EOP == getch()) {
    Serial.print((char)STK_INSYNC);
    Serial.print((char)STK_OK);
  } 
  else {
    error_inc();
    Serial.print((char)STK_NOSYNC);
  }
}

void breply(uint8_t b) {
  if (CRC_EOP == getch()) {
    Serial.print((char)STK_INSYNC);
    Serial.print((char)b);
    Serial.print((char)STK_OK);
  } 
  else {
    error_inc();
    Serial.print((char)STK_NOSYNC);
  }
}

void get_version(uint8_t c) {
  switch(c) {
  case 0x80:
    breply(HWVER);
    break;
  case 0x81:
    breply(SWMAJ);
    break;
  case 0x82:
    breply(SWMIN);
    break;
  case 0x93:
    breply('S'); // serial programmer
    break;
  default:
    breply(0);
  }
}

void set_parameters() {
  // call this after reading paramter packet into buff[]
  param.devicecode = buff[0];
  param.revision   = buff[1];
  param.progtype   = buff[2];
  param.parmode    = buff[3];
  param.polling    = buff[4];
  param.selftimed  = buff[5];
  param.lockbytes  = buff[6];
  param.fusebytes  = buff[7];
  param.flashpoll  = buff[8]; 
  // ignore buff[9] (= buff[8])
  // following are 16 bits (big endian)
  param.eeprompoll = beget16(&buff[10]);
  param.pagesize   = beget16(&buff[12]);
  param.eepromsize = beget16(&buff[14]);

  // 32 bits flashsize (big endian)
  param.flashsize = buff[16] * 0x01000000
    + buff[17] * 0x00010000
    + buff[18] * 0x00000100
    + buff[19];

}

void start_pmode() {
  spi_init();
  // following delays may not work on all targets...
  pinMode(RESET, OUTPUT);
  digitalWrite(RESET, HIGH);
  pinMode(SCK, OUTPUT);
  digitalWrite(SCK, LOW);
  delay(50);
  digitalWrite(RESET, LOW);
  delay(50);
  pinMode(MISO, INPUT);
  pinMode(MOSI, OUTPUT);
  spi_transaction(0xAC, 0x53, 0x00, 0x00);
  pmode = 1;
}

void end_pmode() {
  pinMode(MISO, INPUT);
  pinMode(MOSI, INPUT);
  pinMode(SCK, INPUT);
  pinMode(RESET, INPUT);
  pmode = 0;
}

void universal() {
  int w;
  uint8_t ch;

  fill(4);
  ch = spi_transaction(buff[0], buff[1], buff[2], buff[3]);
  breply(ch);
}

void flash(uint8_t hilo, int addr, uint8_t data) {
  spi_transaction(0x40+8*hilo, 
  addr>>8 & 0xFF, 
  addr & 0xFF,
  data);
}
void commit(int addr) {
  if (PROG_FLICKER) {
    prog_lamp(LOW);
  }
  spi_transaction(0x4C, (addr >> 8) & 0xFF, addr & 0xFF, 0);
  if (PROG_FLICKER) {
    delay(PTIME);
    prog_lamp(HIGH);
  }
}

//#define _current_page(x) (curr_addr & 0xFFFFE0)
int current_page(int addr) {
  if (param.pagesize == 32)  return curr_addr & 0xFFFFFFF0;
  if (param.pagesize == 64)  return curr_addr & 0xFFFFFFE0;
  if (param.pagesize == 128) return curr_addr & 0xFFFFFFC0;
  if (param.pagesize == 256) return curr_addr & 0xFFFFFF80;
  return curr_addr;
}


void write_flash(int length) {
  fill(length);
  if (CRC_EOP == getch()) {
    Serial.print((char) STK_INSYNC);
    Serial.print((char) write_flash_pages(length));
  } 
  else {
    error_inc();
    Serial.print((char) STK_NOSYNC);
  }
}

uint8_t write_flash_pages(int length) {
  int x = 0;
  int page = current_page(curr_addr);
  while (x < length) {
    if (page != current_page(curr_addr)) {
      commit(page);
      page = current_page(curr_addr);
    }
    flash(LOW, curr_addr, buff[x++]);
    flash(HIGH, curr_addr, buff[x++]);
    curr_addr++;
  }

  commit(page);

  return STK_OK;
}

uint8_t write_eeprom(int length) {
  // here is a word address, get the byte address
  int start = curr_addr * 2;
  int remaining = length;
  if (length > param.eepromsize) {
    error_inc();
    return STK_FAILED;
  }
  while (remaining > EECHUNK) {
    write_eeprom_chunk(start, EECHUNK);
    start += EECHUNK;
    remaining -= EECHUNK;
  }
  write_eeprom_chunk(start, remaining);
  return STK_OK;
}

// write (length) bytes, (start) is a byte address
uint8_t write_eeprom_chunk(int start, int length) {
  // this writes byte-by-byte,
  // page writing may be faster (4 bytes at a time)
  fill(length);
  prog_lamp(LOW);
  for (int x = 0; x < length; x++) {
    int addr = start+x;
    spi_transaction(0xC0, (addr>>8) & 0xFF, addr & 0xFF, buff[x]);
    delay(45);
  }
  prog_lamp(HIGH); 
  return STK_OK;
}

void program_page() {
  char result = (char) STK_FAILED;
  int length = 256 * getch();
  length += getch();
  char memtype = getch();
  // flash memory @curr_addr, (length) bytes
  if (memtype == 'F') {
    write_flash(length);
    return;
  }
  if (memtype == 'E') {
    result = (char)write_eeprom(length);
    if (CRC_EOP == getch()) {
      Serial.print((char) STK_INSYNC);
      Serial.print(result);
    } 
    else {
      error_inc();
      Serial.print((char) STK_NOSYNC);
    }
    return;
  }
  Serial.print((char)STK_FAILED);
  return;
}

uint8_t flash_read(uint8_t hilo, int addr) {
  return spi_transaction(0x20 + hilo * 8,
  (addr >> 8) & 0xFF,
  addr & 0xFF,
  0);
}

char flash_read_page(int length) {
  for (int x = 0; x < length; x+=2) {
    uint8_t low = flash_read(LOW, curr_addr);
    Serial.print((char) low);
    uint8_t high = flash_read(HIGH, curr_addr);
    Serial.print((char) high);
    curr_addr++;
  }
  return STK_OK;
}

char eeprom_read_page(int length) {
  // here again we have a word address
  int start = curr_addr * 2;
  for (int x = 0; x < length; x++) {
    int addr = start + x;
    uint8_t ee = spi_transaction(0xA0, (addr >> 8) & 0xFF, addr & 0xFF, 0xFF);
    Serial.print((char) ee);
  }
  return STK_OK;
}

void read_page() {
  char result = (char)STK_FAILED;
  int length = 256 * getch();
  length += getch();
  char memtype = getch();
  if (CRC_EOP != getch()) {
    error_inc();
    Serial.print((char) STK_NOSYNC);
    return;
  }
  Serial.print((char) STK_INSYNC);
  if (memtype == 'F') result = flash_read_page(length);
  if (memtype == 'E') result = eeprom_read_page(length);
  Serial.print(result);
  return;
}

void read_signature() {
  if (CRC_EOP != getch()) {
    error_inc();
    Serial.print((char) STK_NOSYNC);
    return;
  }
  Serial.print((char) STK_INSYNC);
  uint8_t high = spi_transaction(0x30, 0x00, 0x00, 0x00);
  Serial.print((char) high);
  uint8_t middle = spi_transaction(0x30, 0x00, 0x01, 0x00);
  Serial.print((char) middle);
  uint8_t low = spi_transaction(0x30, 0x00, 0x02, 0x00);
  Serial.print((char) low);
  Serial.print((char) STK_OK);
}
//////////////////////////////////////////
//////////////////////////////////////////


////////////////////////////////////
////////////////////////////////////
int avrisp() { 
  uint8_t data, low, high;
  uint8_t ch = getch();
  switch (ch) {
  case '0': // signon
    error_rst();
    empty_reply();
    break;
  case '1':
    if (getch() == CRC_EOP) {
      Serial.print((char) STK_INSYNC);
      Serial.print("AVR ISP");
      Serial.print((char) STK_OK);
    }
    break;
  case 'A':
    get_version(getch());
    break;
  case 'B':
    fill(20);
    set_parameters();
    empty_reply();
    break;
  case 'E': // extended parameters - ignore for now
    fill(5);
    empty_reply();
    break;

  case 'P':
    start_pmode();
    empty_reply();
    break;
  case 'U': // set address (word)
    curr_addr = getch();
    curr_addr += 256 * getch();
    empty_reply();
    break;

  case 0x60: //STK_PROG_FLASH
    low = getch();
    high = getch();
    empty_reply();
    break;
  case 0x61: //STK_PROG_DATA
    data = getch();
    empty_reply();
    break;

  case 0x64: //STK_PROG_PAGE
    program_page();
    break;

  case 0x74: //STK_READ_PAGE 't'
    read_page();    
    break;

  case 'V': //0x56
    universal();
    break;
  case 'Q': //0x51
    error_rst();
    end_pmode();
    empty_reply();
    break;

  case 0x75: //STK_READ_SIGN 'u'
    read_signature();
    break;

    // expecting a command, not CRC_EOP
    // this is how we can get back in sync
  case CRC_EOP:
    error_inc();
    Serial.print((char) STK_NOSYNC);
    break;

    // anything else we will return STK_UNKNOWN
  default:
    error_inc();
    if (CRC_EOP == getch()) 
      Serial.print((char)STK_UNKNOWN);
    else
      Serial.print((char)STK_NOSYNC);
  }
}

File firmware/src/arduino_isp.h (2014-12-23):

//
// ArduinoISP.h
//
// Used to turn a standard Arduino development board or equivalent into a
// full-fledged AVR programmer. This is useful both for burning the bootloader
// to a blank ATMega328, as well as programming ATTiny's which are too small or
// lack a bootloader altogether.
//

#ifndef _ARDUINO_ISP_H
#define _ARDUINO_ISP_H

#define SERIAL_BAUD 19200

// Pin definitions needed besides the standard SCK, MISO, & MOSI pins for SPI
#define RESET     10
#define LED_HB    4
#define LED_ERR   3
#define LED_PMODE 2

// Do we flash the programming light while programming?
#define PROG_FLICKER true

// This is the version of the AVR programmer we report to the host
#define HWVER 2
#define SWMAJ 1
#define SWMIN 18

// STK Definitions
#define STK_OK      0x10
#define STK_FAILED  0x11
#define STK_UNKNOWN 0x12
#define STK_INSYNC  0x14
#define STK_NOSYNC  0x15
#define CRC_EOP     0x20 //ok it is a space...

// Flash all LEDs for this many milliseconds on power-up
#define PTIME 30

// Macro to fetch a 16 bit, big-endian integer from a given address (memcpy is
// hard, I guess?)
#define beget16(addr) (*(addr) * 256 + *((addr)+1))

// Number of bytes written to EEPROM at a time
#define EECHUNK (32)

// Heartbeat parameters. All but the interval parameter are fed into
// analogWrite, which controls the voltage sent to the LED on pin 9. Use these
// to change the min/max/starting brightness, as well as the pulse rate.
const uint8_t HB_STARTING = 128;
const uint8_t HB_MIN = 32;
const uint8_t HB_MAX = 128;
const int8_t HB_DELTA = 8;
const int HB_RATE = 20; //ms

// Structure used to hold results of parsing command packet from host
typedef struct param {
  uint8_t devicecode;
  uint8_t revision;
  uint8_t progtype;
  uint8_t parmode;
  uint8_t polling;
  uint8_t selftimed;
  uint8_t lockbytes;
  uint8_t fusebytes;
  int flashpoll;
  int eeprompoll;
  int pagesize;
  int eepromsize;
  int flashsize;
} 
parameter;

// Function prototypes

void setup();
void heartbeat();
uint8_t error_inc();
uint8_t error_rst();
void loop(void);
uint8_t getch();
void fill(int n);
void pulse(int pin, int times);
void prog_lamp(int state);
void spi_init();
void spi_wait();
uint8_t spi_send(uint8_t b);
uint8_t spi_transaction(uint8_t a, uint8_t b, uint8_t c, uint8_t d);
void empty_reply();
void breply(uint8_t b);
void get_version(uint8_t c);
void set_parameters();
void start_pmode();
void end_pmode();
void universal();
void flash(uint8_t hilo, int addr, uint8_t data);
void commit(int addr);
int current_page(int addr);
void write_flash(int length);
uint8_t write_flash_pages(int length);
uint8_t write_eeprom(int length);
uint8_t write_eeprom_chunk(int start, int length);
void program_page();
uint8_t flash_read(uint8_t hilo, int addr);
char flash_read_page(int length);
char eeprom_read_page(int length);
void read_page();
void read_signature();
int avrisp(); 

#endif

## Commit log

2014-12-23 Initial commit of first four (!) PCB revs.
    1.0) Never saw production, unfinished.
    2.0) Fabbed, but holes for ZIF sockets & many other components far too
    small. What I get for not measuring. :P
    3.0) Holes enlarged, relayout, etc. Works kinda, but clock stuff is
    completely bogus since I added a motherfuckton of parasitic
    capacitance/inductance with all those traces. If your chip expects a
    clock signal after reset, it ain't getting it.
    4.0) Latest version.
    * Eliminates 20 pin socket (have yet to use an ATTiny 2314 or 4313)
    * Drops clock signal from all ATTiny's,
    * Remove 3.3V support since basically all Atmel's chips I'm working
    with can handle the entire voltage range. Should re-a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
    [ziffy_board.brd, ziffy_board.sch, ziffy_board_v2.brd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]
2014-12-23 initial firmware checkin with minor tweaks from the arduino dist to get it to compile and eliminate some errors
    [arduino_isp.h, arduino_isp.ino]
2014-12-23 changing pin defs for rev4 board
2014-12-26 mark 5 now with physical big-ass switch. vcc routing done only
    [ziffy_board_v5.brd, ziffy_board_v5.sch]
2014-12-26 most routing complete, just the ratsnest near the switch left (ugh)
    [ziffy_board_v5.brd, ziffy_board_v5.sch]
2014-12-27 new version using bus drivers
    [ziffy_board_v6.brd, ziffy_board_v6.sch]
2014-12-27 layout complete for mark 5
    [ziffy_board_v5.brd, ziffy_board_v5.sch]
2015-01-11 more twaddling
    [ziffy_board_v6.brd, ziffy_board_v6.sch]
2015-01-11 routing done! mostly. now trying to return to pin-compat with original code base
    [ziffy_board_v6.brd, ziffy_board_v6.sch]
2015-01-11 more trying to return to pin-compat with original code base
    [ziffy_board_v6.brd]
2015-01-11 layout complete. replaced most of the surface mount caps w/PTH ones. still debating resistors for LEDs.
    [ziffy_board_v6.brd, ziffy_board_v6.sch]
2015-01-11 trying all the angles (ba-dum-tish)
    [ziffy_board_v6.brd, ziffy_board_v6.sch]
2015-01-11 re-layered values so they actually make it to the silkscreen layer
    [ziffy_board_v6.brd]
2015-01-11 update the damn library b/c apparently i hadn't merged all teh changes from there either.
    [ziffy_board_v6.brd, ziffy_board_v6.sch]
2015-01-12 touch ups, edge routering, etc.
    [ziffy_board_v5.brd, ziffy_board_v5.sch]
2015-01-12 silk screen, ready for fab i think
    [ziffy_board_v5.brd]
2015-01-12 oshpark: wat
    [ziffy_board_v5.brd, ziffy_board_v5.sch]

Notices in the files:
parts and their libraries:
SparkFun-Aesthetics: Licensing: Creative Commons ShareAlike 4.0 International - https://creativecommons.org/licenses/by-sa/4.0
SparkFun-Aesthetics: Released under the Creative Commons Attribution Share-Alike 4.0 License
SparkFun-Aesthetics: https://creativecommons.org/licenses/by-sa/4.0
